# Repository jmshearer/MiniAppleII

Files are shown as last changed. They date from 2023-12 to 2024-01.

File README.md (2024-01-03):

# Miniature Apple II with working screen
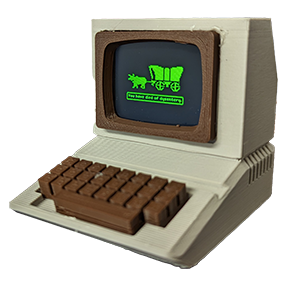
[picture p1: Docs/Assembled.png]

The Miniature Apple IIe project was inspired by this [Tiny Raspberry Pi Zero Mac](https://www.instructables.com/Making-a-Tiny-Mac-From-a-Raspberry-Pi-Zero) and many other attempts at making Pi-based Apple computers, including many Apple II's.  I found the screen on the working Mac model to be too small to really be usable and, while certainly impressive, generally unnecessary to trigger all of the nostalgia endorphins.  This project attempts to create a simple-to-build and cost-effect (less than $20) Apple II that can be used to display some sweet, sweet nostalgia (hello, Oregon Trail) or as a platform for more advanced projects.  In addition to being cheap ($5), the XIAO ESP32C23 microcontroller has BLE and Wifi so it could serve up some pretty impressive content.

### A note on history...
The model is technically based on an original Apple II with an Apple Monitor II, a green monochrome CRT.  The software presents an amalgam of several of the Apple II computers, notably the Apple IIs and Apple IIe with IIgs-style graphics.  Think of it as a mid-80's-era Apple IIe computer, capturing the nostalgic bits of several pieces of the early Apple II line, as opposed to a strict recreation of a specific model.

## Assemble The Model

### Materials
- 3D-printed Apple II case and components.
  - [Beige PLA](https://www.amazon.com/gp/product/B09TR8N5T2/ref=ppx_yo_dt_b_search_asin_title?ie=UTF8&psc=1)
  - [Brown PLA](https://www.amazon.com/gp/product/B0991VV5SX/ref=ppx_yo_dt_b_search_asin_title?ie=UTF8&psc=1) - This isn't the most accurate color, but it's what I had on hand and it fits the "80's nostalgia" theme.
  - Originally based on [Mini Apple II](https://www.thingiverse.com/thing:3643947) but heavily modified to support the electronics.
- XIAO ST7789V2 LCD Display [Seeed Studio](https://www.seeedstudio.com/1-69inch-240-280-Resolution-IPS-LCD-Display-Module-p-5755.html) | [GitHub](https://github.com/limengdu/XIAO_ST7789V2_LCD_Display/) | [Buy on Digikey](https://www.digikey.com/en/products/detail/seeed-technology-co-ltd/104990802/21526011)
- XIAO ESP32C23 Microcontroller [Seeed Studio](https://www.seeedstudio.com/Seeed-XIAO-ESP32C3-p-5431.html) | [Buy on digikey](https://www.digikey.com/en/products/detail/seeed-technology-co-ltd/113991054/16652880)
- M2x6mm screws (optional) [Here's a nice set](https://www.amazon.com/gp/product/B014OO5KQG/ref=ppx_yo_dt_b_search_asin_title?ie=UTF8&psc=1)

### Printing
Be sure to support the model internally when printing.  It took my Ender 3 about 2.5 hrs to print the case, which is perfect for assembling the electronics and programming it while it's printing.

### Connecting LCD to the Microcontroller
| LCD | Microcontroller | Color* |
|-----|-----|---|
| VCC | 3V3 | Purple |
| GND | GND | White  |
| DIN | D10 | Green  |
| CLK | D8  | Orange |
| CS  | D1  | Yellow |
| DC  | D3  | Blue   |
| RST | D0  | Brown  |
| BL  | D6  | Gray   |

*=Be sure to verify color codes against the actual cable.

```
Viewing from the rear of the PCB (face down).  Double-check color codes.
      +-----------+
 GRY -|D6       D7|-
     -|D5       D8|- ORN
     -|D4       D9|-
 BLU -|D3      D10|- GRN
     -|D2      3V3|- PUR
 YEL -|D1      GND|- WHT
 BRN -|D0      USB|-
      +---|USB|---+
          +---+
```

If you're just getting started with electronics, it's a good idea to solder the headers onto the PCB and connect the LCD via the included breakout cable.  More experienced makers can cut the cable down to about 1.5" and solder directly onto the microcontroller.  Note that the controller will be "upside down" in the case; this orientation supports using the included headers and also wires soldered directly to the back.  A notch in the XIAO "tray" inside the unit allows for the antenna to be attached.  I strongly recommend connecting the electronics and programming (next step) before assembling into the printed case, tempting as it might be.

### Programming
1. Follow the instructions on [Seeed's Wiki](https://wiki.seeedstudio.com/XIAO_ESP32C3_Getting_Started/) to set up the Arduino development environment.
2. Clone this repo and open one of the files from the Controller path in Arduino Studio.
3. Select the appropriate board (probably XIAO ESP32C3) and port (probably a COMn port).
4. Upload the INO to the controller and verify that it works.

### Assembly
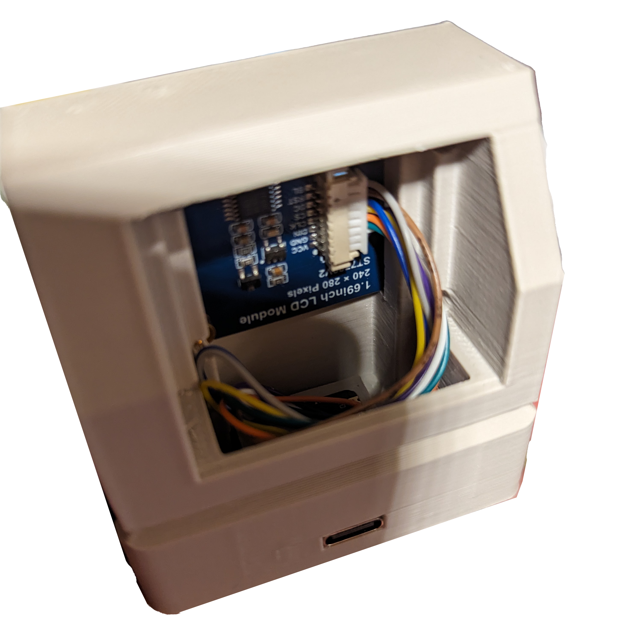
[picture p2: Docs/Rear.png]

1. **Feed the programmed & tested microcontroller through the front of the unit.**  Do not actually attach the LCD to the plastic yet (just leave it dangling)
2. **Snap the microcontroller "upside-down" into the holder by the USB port opening.**  This can be a bit tricky; you will need to make sure the USB-C port protrudes into the wall of the computer and will need to press firmly on the rear of the PCB to snap it below the nubs holding it in place.  If the microcontroller breaks loose during normal operation due to strain on the USB port, you can add a dab of hot glue at the rear of the PCB to keep it from popping up.
4. **Install the LCD.**  The posts on the LCD should line up and slide inside of the holes on the monitor face.  Optionally screw in the LCD using the M2x6mm screws; be careful to not overtighten.
5. **Position the optional wifi antenna** such that it is not bent and that the solder on the antenna will never come in contact with other electronics.  I recommend positioning it vertically with its solder-free side against the LCD.  Optionally attach the antenna with the included adhesive backing.
6. **Snap the plastic pieces into place;** bezel, keyboard, and CRT back, being careful not to pinch any wires or the antenna with the CRT back.  The ability to snap the pieces in place is a significant departure from the original 3D model.  Depending on your printer and settings, you may need to adjust tolerances.

## Customizing the Software
### Custom Graphics
Loading raster graphics onto the unit is not terribly elegant but should be straightforward with the included python script.
1. Create a 260x240 pixel image
2. Convert the image to 16-bit 5-6-5 depth and export as hex using the included Python script  For example:
```
ImageConvert.py OregonTrail/oregon1.png
```
3. Open the result (out.txt) and paste into graphics.cpp, cleaning up syntax (commas, brackets, etc)

### Future Additions
Some things I'd like to do (also known as "exercises left for the reader")
- Add image compression/decompression--A single uncompressed image takes about 600k but even basic RLE compression could reduce that significantly.  I have a RLE-ish compression scheme in mind.
- Use Bluetooth or wifi for...something--make it a clock / weather station / subway tracker / whatever.
- Implement USB host functionality and interface with HID devices and/or Bluetooth HID devices.
- Make an actual BASIC or LOGO interpreter.  The Apple II had 4K...the XIAO has 4M!
- Make an actual Apple II emulator...this [appears to be possible](https://github.com/dpeckett/arduino-appleii) so somebody should go for it!

## Additional References
- [Arduino Library .h File](https://github.com/limengdu/XIAO_ST7789V2_LCD_Display/blob/main/st7789v2.h)
- [Apple IIe LOGO emulator](https://www.scullinsteel.com/apple//e#logo)
- [Apple II emulator on Arduino](https://github.com/dpeckett/arduino-appleii) - Future aspirations!

## Send Some Love (in the form of coffee)
<a href="https://www.buymeacoffee.com/jmshearer" target="_blank">Buy Me A Coffee</a>

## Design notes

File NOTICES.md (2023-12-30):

# Third-Party Notices

This project incorporates material from the projects listed below. The original material was modified to create derived material used in this project. The kind gesture of these open-source contributors is gratefully acknowledged.

---

## Mini Apple ][ Model

- **License**: [Creative Commons - Attribution - Non-Commercial license](https://creativecommons.org/licenses/by-nc/4.0/)
- **Source**: [Thingiverse](https://www.thingiverse.com/thing:3643947)
- **Author**: RabitEngineering

**You are free to:**
- Share — copy and redistribute the material in any medium or format
- Adapt — remix, transform, and build upon the material
The licensor cannot revoke these freedoms as long as you follow the license terms.

**Under the following terms:**
- Attribution — You must give appropriate credit , provide a link to the license, and indicate if changes were made . You may do so in any reasonable manner, but not in any way that suggests the licensor endorses you or your use.
- NonCommercial — You may not use the material for commercial purposes .
No additional restrictions — You may not apply legal terms or technological measures that legally restrict others from doing anything the license permits.

**Notices:**
You do not have to comply with the license for elements of the material in the public domain or where your use is permitted by an applicable exception or limitation .

No warranties are given. The license may not give you all of the permissions necessary for your intended use. For example, other rights such as publicity, privacy, or moral rights may limit how you use the material.

--

## Oregon Trail Artwork

This repository includes thumbnail graphics from "The Oregon Trail" for demonstration and placeholder purposes only. These graphics may be copyrighted material and are included under Fair Use guidelines for educational and non-commercial demonstration purposes.

**Copyright Notice:**
"The Oregon Trail" graphics may be copyrighted material. All rights related to "The Oregon Trail" graphics, including but not limited to copyright ownership, are the property of their respective owners.

**Fair Use Disclaimer:**
The use of "The Oregon Trail" graphics in this software package is intended for non-commercial, educational, and demonstration purposes only. This use should not be construed as a challenge to the ownership of the copyrights by the original copyright holders.

**Limitations of Use:**
The graphics from "The Oregon Trail" included in this package are for demonstration purposes within the context of this software only.
Users of this software package are advised against extracting, copying, or using these graphics for any other purposes outside the scope of this software.
Redistribution of these graphics as part of any other software or project, whether open-source or commercial, is strictly prohibited unless authorized by the copyright holders.

***Acknowledgments:**
This software package includes graphics from "The Oregon Trail," originally developed by the Minnesota Educational Computing Consortium (MECC).

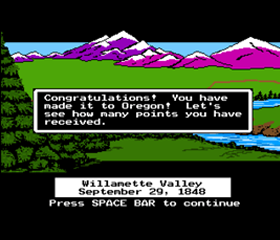
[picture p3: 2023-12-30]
Graphics/OregonTrail/oregon7.png

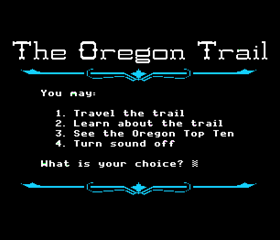
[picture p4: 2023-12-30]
Graphics/OregonTrail/oregon1.png

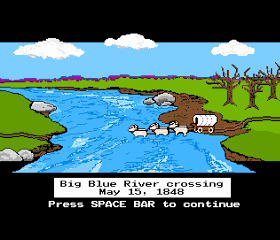
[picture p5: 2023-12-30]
Graphics/OregonTrail/oregon5.png

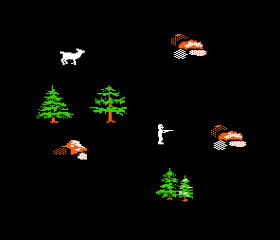
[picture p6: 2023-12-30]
Graphics/OregonTrail/oregon4.png

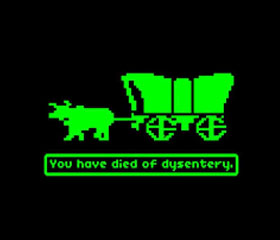
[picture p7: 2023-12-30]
Graphics/OregonTrail/oregon4.jpg

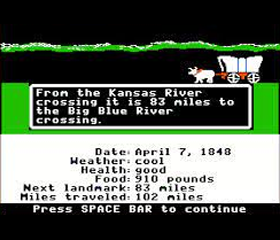
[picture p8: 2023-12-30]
Graphics/OregonTrail/oregon3.png

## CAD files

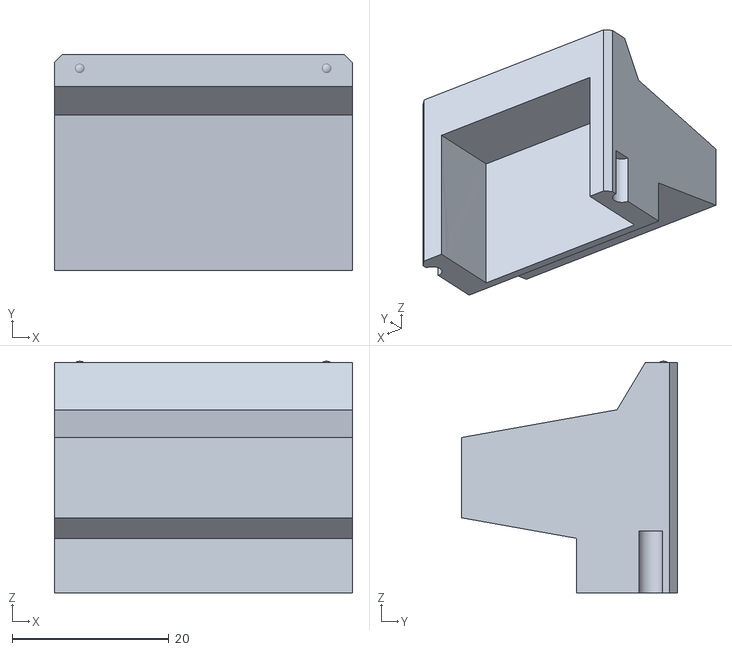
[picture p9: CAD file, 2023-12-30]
Model/Monitor Rear.stl
38.0 x 27.5 x 29.5

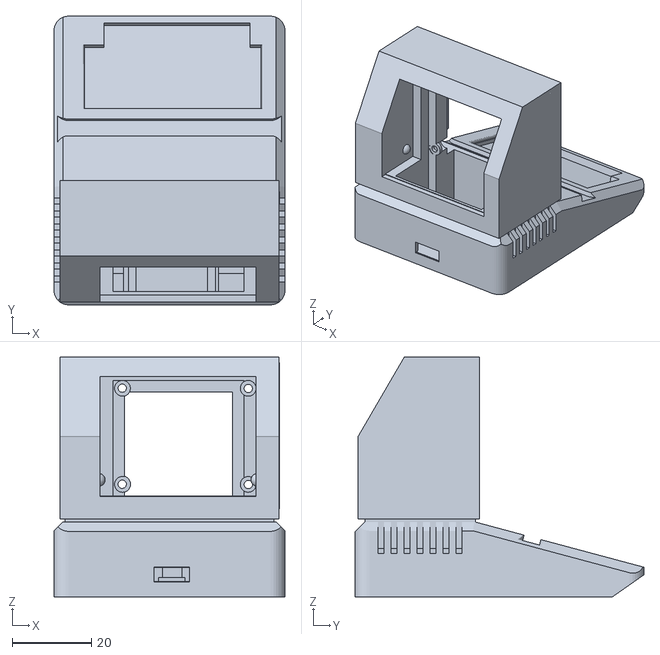
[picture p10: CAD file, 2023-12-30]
Model/Computer Body.stl
58.4 x 73.0 x 60.6

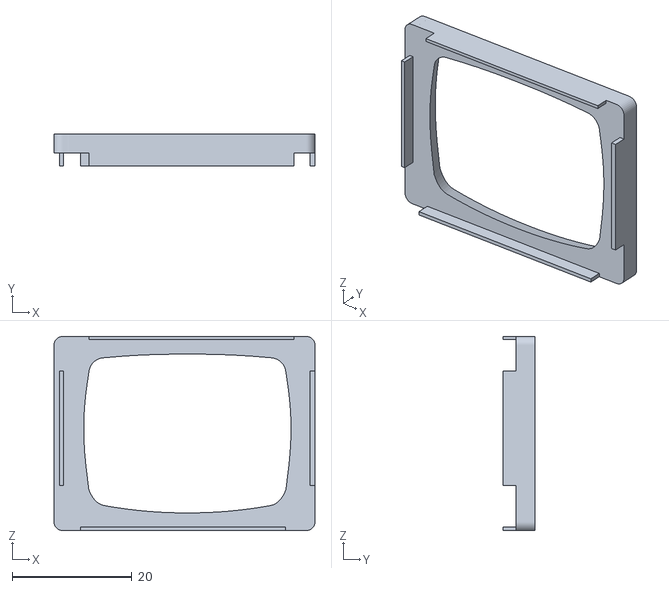
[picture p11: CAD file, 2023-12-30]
Model/Monitor Bezel.stl
43.7 x 5.38 x 32.5

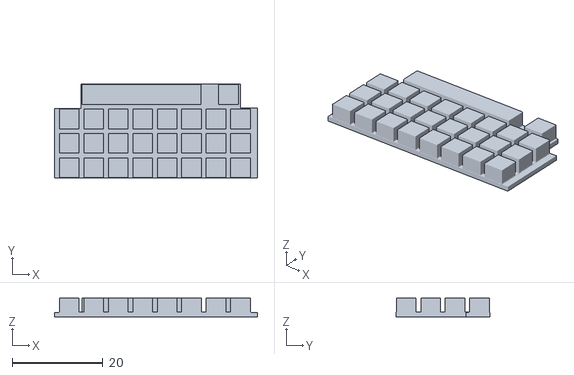
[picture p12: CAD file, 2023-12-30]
Model/Keyboard.stl
44.8 x 20.8 x 4.12

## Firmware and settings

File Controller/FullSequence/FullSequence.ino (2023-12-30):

#include <st7789v2.h>
#include "SPI.h"
#include "graphics.h"

st7789v2 lcd;

int lastRandomNumber=0;

void setup() {  
  lcd.SetRotate(270);
  lcd.Init();
  lcd.SetBacklight(100);
  lcd.Clear(BLACK);
  lcd.DrawString_EN(80, 20, "Apple ][", &Font16, BLACK, GREEN);
  delay(2500);
  lcd.DrawString_EN(80, 20, "        ", &Font16, BLACK, GREEN);  
  randomSeed(analogRead(0));  
}

void loop() {     

  //Come up with a random action that is different than the previous one
  int randomNumber;
  do {
    randomNumber = random(1, 5); 
  } while (randomNumber == lastRandomNumber);
  lastRandomNumber = randomNumber;    


  //Perform the action.  Note that each action should return the screen to black
  switch(randomNumber){
    case 1:
      showAbout();
      break;
    case 2:
      showOregon();
      break;
    case 3:
      showCat();
      break;
    case 4:
      showLOGO();
      break;
  }  
}


//LOGO simulator
void showLOGO() {  
  lcd.Clear(BLACK);
  int shape = random(1,3);  
  TypeCommandWait(20,"]BRUN LOGO",0);
  lcd.DrawString_EN(10, 20,"             ", &Font16, BLACK, GREEN);
    
  switch(shape){
    case 1:
      TypeCommandWait(150,"?TO STAR",0);
      TypeCommandWait(170,">REPEAT 5 [",0);
      TypeCommandWait(190, ">FD 5 RT 144",0);      
      TypeCommandWait(210,">]",0);  
      
      lcd.DrawString_EN(10, 210,"             ", &Font16, BLACK, GREEN);
      lcd.DrawString_EN(10, 190,">]           ", &Font16, BLACK, GREEN);
      lcd.DrawString_EN(10, 170,">FD 5 RT 144 ", &Font16, BLACK, GREEN);
      lcd.DrawString_EN(10, 150,">REPEAT 5[   ", &Font16, BLACK, GREEN);  
      TypeCommandWait(210,">END",0);  
      
      lcd.DrawString_EN(10, 210,"             ", &Font16, BLACK, GREEN);
      lcd.DrawString_EN(10, 190,"STAR DEFINED ", &Font16, BLACK, GREEN);      
      lcd.DrawString_EN(10, 170,">END         ", &Font16, BLACK, GREEN);      
      lcd.DrawString_EN(10, 150,">]           ", &Font16, BLACK, GREEN);      
      TypeCommandWait(210,"?STAR",0);    

      lcd.DrawString_EN(10, 150,">END         ", &Font16, BLACK, GREEN);      
      lcd.DrawString_EN(10, 170,"STAR DEFINED ", &Font16, BLACK, GREEN);      
      lcd.DrawString_EN(10, 190,"?STAR        ", &Font16, BLACK, GREEN);
      lcd.DrawString_EN(10, 210,"             ", &Font16, BLACK, GREEN);  
        
      logoPlot(5, 144, 50);      

      TypeCommandWait(210,"?",3);
      TypeCommandWait(210,"?BYE",0);

      break;
    case 2:
      TypeCommandWait(150,"?REPEAT 4 [FD 5 RT 90]",0);            
      
      logoPlot(4, 90, 50);

      TypeCommandWait(190,"?",3);
      TypeCommandWait(190,"?BYE",0);
      break;
  }  
  lcd.Clear(BLACK);
}

//logoPlot is used by showLOGO and it more-or-less behaves very similar to the original LOGO software
void logoPlot(int n, float angleIncrement, int length){
  float angle = 0;
  int x =105;
  int y = 80;  
  int xEnd;
  int yEnd;
  for (int i = 0; i < n; i++) {
    // Calculate end point of each line based on angle
    xEnd = x + round(length * cos(radians(angle)));
    yEnd = y + round(length * sin(radians(angle)));

    // Draw the line
    lcd.DrawLine(x, y, xEnd, yEnd, GREEN, DOT_PIXEL_2X2, LINE_STYLE_SOLID);
    delay(100);

    // Update the angle for the next line
    angle += angleIncrement;
    x = xEnd;
    y = yEnd;
  }

  xEnd=xEnd-4;
  yEnd=yEnd+2;

  //Create a "turtle" (poor substitution, but it gets the idea across)
  lcd.DrawLine(xEnd, yEnd, xEnd+8, yEnd, GREEN, DOT_PIXEL_1X1, LINE_STYLE_SOLID);  
  lcd.DrawLine(xEnd, yEnd, xEnd+4, yEnd-8, GREEN, DOT_PIXEL_1X1, LINE_STYLE_SOLID);  
  lcd.DrawLine(xEnd+8, yEnd, xEnd+4, yEnd-8, GREEN, DOT_PIXEL_1X1, LINE_STYLE_SOLID);
}

//Show the Oregon Trail artwork
void showOregon(){
  lcd.Clear(BLACK);    
  TypeCommandWait(20,"]BRUN OREGON",0);
  delay(1500);
  lcd.DrawString_EN(10, 40, "              " , &Font16, BLACK, GREEN);

  lcd.DrawImage(oregon1, 0, 0, 260, 240);   
  delay(2000);
  lcd.DrawImage(oregon2, 0, 0, 260, 240);   
  delay(2000);
  lcd.DrawImage(oregon3, 0, 0, 260, 240);   
  delay(2000);
  lcd.DrawImage(oregon4, 0, 0, 260, 240);   
  delay(2000);
  lcd.DrawImage(oregon5, 0, 0, 260, 240);   
  delay(2000);

  if(random(1,4)==1){
    lcd.DrawImage(oregon7, 0, 0, 260, 240);     
  } else {
    lcd.DrawImage(oregon6, 0, 0, 260, 240);   
  }
  delay(2000);
  lcd.Clear(BLACK);
  lcd.DrawString_EN(10, 20, "]BRUN OREGON", &Font16, BLACK, GREEN);
  TypeCommandWait(40,"]",2);
  TypeCommandWait(40,"]HOME",0);
}

//Show a simple ASCII-art cat
void showCat() {  
  lcd.Clear(BLACK);
  TypeCommandWait(20,"]LOAD CAT.BAS",0);
  TypeCommandWait(40,"]RUN",0);

  delay(500);
  
  lcd.DrawString_EN(30, 60,  "   |\__/,|    (`)", &Font16, BLACK, GREEN);
  lcd.DrawString_EN(30, 80,  "   |o o  |__ _) )", &Font16, BLACK, GREEN);
  lcd.DrawString_EN(30, 100, " _.( T   )  `  /", &Font16, BLACK, GREEN);
  lcd.DrawString_EN(30, 120, "((_ `^--' /_<  \\", &Font16, BLACK, GREEN);
  lcd.DrawString_EN(30, 140, "`` `-'(((/  (((/", &Font16, BLACK, GREEN);  

  delay(1500);

  TypeCommandWait(180,"]",3);
  
  TypeCommandWait(180,"]HOME",0);    
}


//Show an "About" screen
void showAbout() {  
  lcd.Clear(BLACK);    
  TypeCommandWait(20,"]LOAD ABOUT.BAS",0);
  TypeCommandWait(40,"]RUN",0);

  delay(500);
  
  lcd.DrawString_EN(30, 80,  " Mini Apple II", &Font16, BLACK, GREEN);
  lcd.DrawString_EN(30, 100,  " (C) Shearer", &Font16, BLACK, GREEN);
  lcd.DrawString_EN(30, 120, "", &Font16, BLACK, GREEN);
  lcd.DrawString_EN(30, 140, "       2023", &Font16, BLACK, GREEN);  
  delay(1500);

  TypeCommandWait(180,"]",3);
  
  TypeCommandWait(180,"]HOME",0);    
}

//Pretend to "type" a command and then wait for sec
void TypeCommandWait(int y, String cmd, int sec) {
  String temp;
  
  for (int i = 1; i <= cmd.length(); i++) {
    // Get the substring from the start to the current position
    temp = cmd.substring(0, i) + char(176);
    // Display the substring on the LCD
    lcd.DrawString_EN(10, y, temp.c_str(), &Font16, BLACK, GREEN);
    // Delay for a random time between 150ms and 200ms to simulate variable typing speed
    delay(random(150, 201));    
  }

  //Add the blinking cursor
  String withCursor = cmd + char(176);
  String withoutCursor = cmd + " ";
  for(int i=0; i <= sec*2; i++){
    lcd.DrawString_EN(10, y, withoutCursor.c_str(), &Font16, BLACK, GREEN);
    delay(500);
    lcd.DrawString_EN(10, y, withCursor.c_str(), &Font16, BLACK, GREEN);
    delay(500);
  }
  lcd.DrawString_EN(10, y, withoutCursor.c_str(), &Font16, BLACK, GREEN);
}
